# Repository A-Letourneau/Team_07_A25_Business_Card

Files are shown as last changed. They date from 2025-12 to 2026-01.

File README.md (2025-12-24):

# C3I A25\_Business\_Card

Concours de Conception de Circuits Imprimés – Université de Sherbrooke, Automne 2025

## Thème : Carte professionnelle (Business Card)

## Contenu

* Schéma électrique (PDF)
* Fichiers Gerber du PCB + projet EDA OU PDF coloré des couches
* Photo(s) du PCB assemblé (avec et sans boîtier)
* BOM conforme aux normes C3I
* Documentation complète du projet

---

## Contacts

* Alexis Létourneau – Participant – `leta0145@usherbrooke.ca`

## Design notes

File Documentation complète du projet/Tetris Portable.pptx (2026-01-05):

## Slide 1

Tetris portable

Présentation par : équipe 7
Alexis Létourneau
Groupe technique C3I

## Déroulement de la présentation

C3I – Votre nom d’équipe

1

Présentation globale

2

Présentation du projet

3

Respect des contraintes

4

Démonstration

5

Période de
questions

## Présentation globale

- Tetris 9x16
- Portable
- Alimenté par un téléphone
- Peu cher

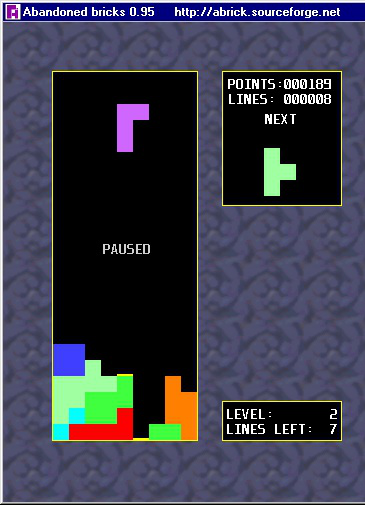
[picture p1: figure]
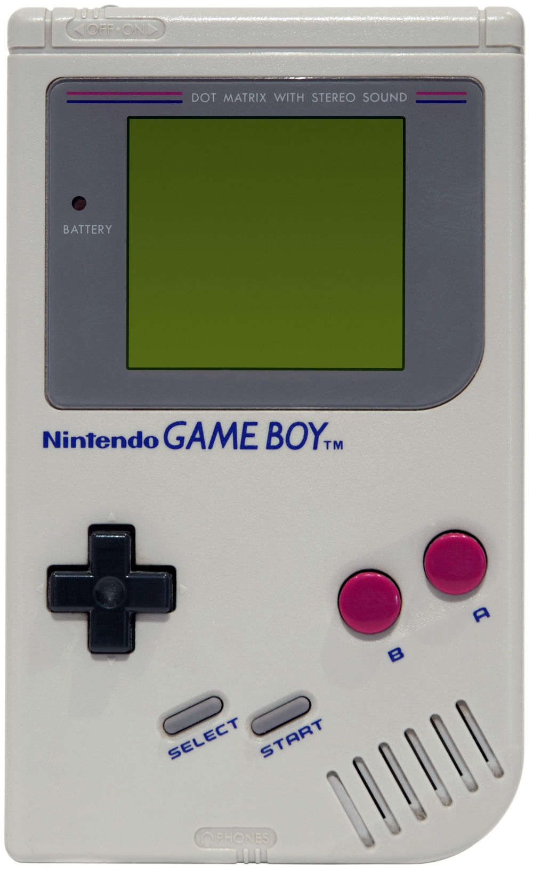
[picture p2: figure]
Looking Back on Nintendo's Game Boy 25 Years Later - Newegg Insider

C3I – Alexis Létourneau

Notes: 26.37$

## Déroulement de la présentation

1

Présentation globale

2

Présentation du projet

3

Respect des contraintes

4

Démonstration

5

Période de
questions

## Le ESP32-C3-WROOM-02

- Communication I2c pour le contrôle des DEL
- Facilité d’utilisation
- Facilité d’intégration
- Pull up intégrée

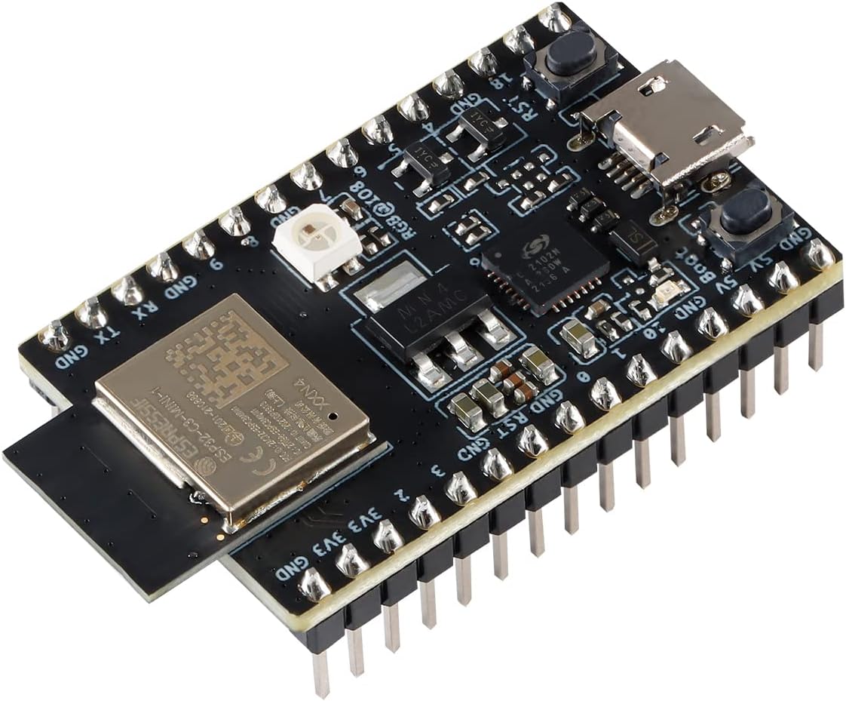
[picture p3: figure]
Esp32 C3 Dev Board

## Programmation

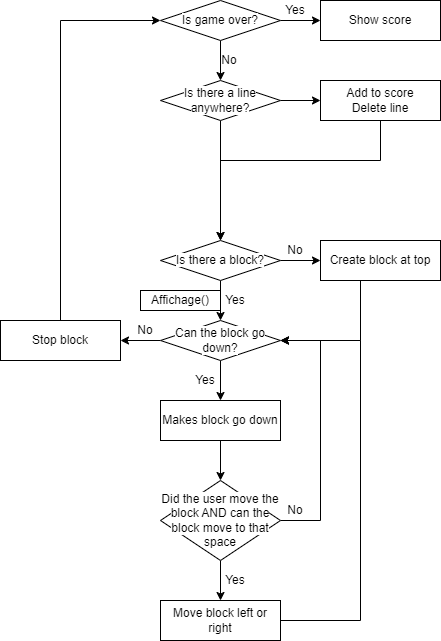
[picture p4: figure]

## PCB

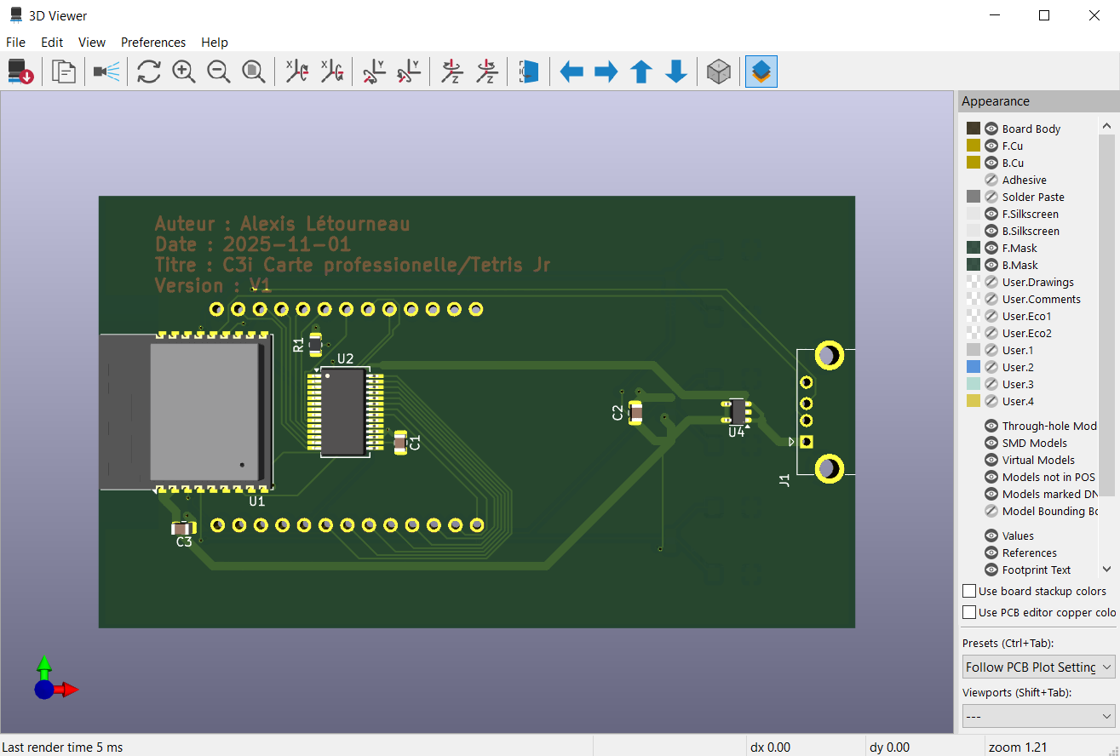
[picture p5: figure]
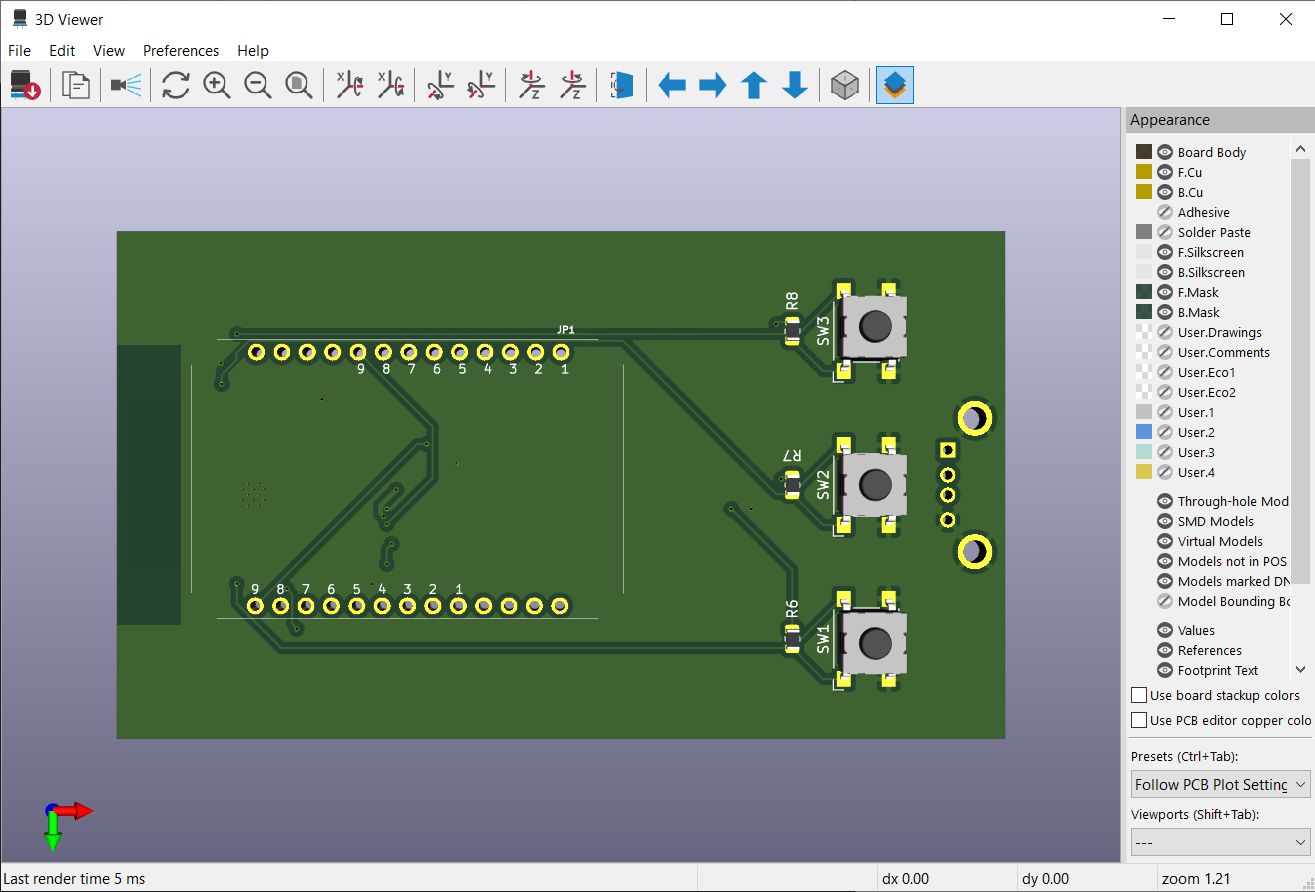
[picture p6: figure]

## Déroulement de la présentation

1

Présentation globale

2

Présentation du projet

3

Respect des contraintes

4

Démonstration

5

Période de
questions

## Respect des contraintes

- Budget
  - Pièces électroniques
  - PCB
- Taille
  - Ergonomique

## Déroulement de la présentation

1

Présentation globale

2

Présentation du projet

3

Respect des contraintes

4

Démonstration

5

Période de
questions

## Démo!

- Expliquez brièvement comment utiliser votre produit, puis faites une démonstration. Il se peut que les juges tests votre produit aussi.
- 1 slide

## Déroulement de la présentation

1

Présentation globale

2

Présentation du projet

3

Respect des contraintes

4

Démonstration

5

Période de
questions

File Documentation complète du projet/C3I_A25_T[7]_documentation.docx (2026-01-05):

UNIVERSITÉ DE SHERBROOKE

Groupe technique

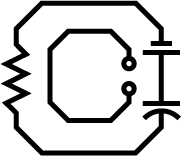
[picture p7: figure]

Compétition de Conception de

Circuits Imprimés

# Documentation C3I A25

Tetris Portable

Rédigé par :

Équipe #7,

Alexis Létourneau

En date du : 5 janvier 2026

Table des matières

# 1. Introduction

## Contexte d’application

Le projet est un jeu de Tetris Portable de la taille d’une carte professionnelle. Il sera utilisé d’une manière similaire à une « Gameboy » mais avec un seul jeu de Tetris. L’idée est d’avoir une toute petite carte qui peut démontrer mon savoir de PCB en utilisant un jeu connu par la plupart de la population. Un client utiliserait la carte en branchant la prise USB de la carte dans une source de tension, comme un bloc-chargeur de téléphone, et puis appuiera sur les 3 boutons pour jouer au jeu. Pour plus d’information sur comment jouer à Tetris : https://fr.wikihow.com/jouer-%C3%A0-Tetris. Il faut noter que la fonction pivoter ne marche pas pour ce projet.

## Contraintes du projet

### 1.1.1. Contraintes technologiques

Le C3I limite la taille du PCB à 88,9 mm x 50,8 mm et enlève des points avec l’utilisation d’un « DevBoard ». Cela fait que la carte peut au mieux contenir un petit MCU, comme un ESP-32. La petite taille limite aussi l’ergonomie et la quantité des contrôles actionnables, comme les boutons, sur le PCB

### 1.1.2. Contraintes de temps et de budget

Le cout totale de la session était 125$, dont 50$ maximale en pièces électroniques. Cela était amplement assez pour couvrir les frais des pièces électroniques, même avec des pièces électroniques en extra.

Le temps lui était plus serré, même si nous avions la session au complet, la commande de PCB et des pièces électroniques s’est fait en mi-novembre. La mi-novembre est aussi la période la plus chargé en termes de projet en génie et d’examen.

## Description du produit réalisé

Ma carte professionnel de Tetris portable est contrôlé par un microcontrôleur ESP32-WROOM-32E qui lui contrôle un contrôleur IS31FL3731-SA. Le IS31FL3731-SA contrôle l’affichage de 144 DEL Charlie-Plex via I2c pour afficher le jeu de Tetris. Le microcontrôleur est alimenté par une prise USB-A 5V qui est ensuite réduit à 3.3V avec un régulateur de tension. Finalement, il y a 3 boutons pour interagir avec le jeu de Tetris.

### 1.1.3. Présentation globale

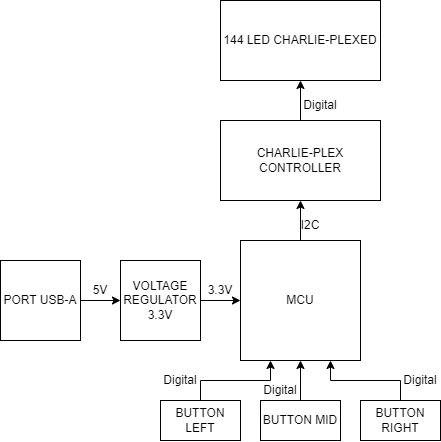
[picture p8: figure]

# 2. Développement

## Conception électronique

### 2.1.1. Choix technologiques

J’ai choisi un ESP32-WROOM-32E comme microcontrôleur car je suis familier avec son utilisation et il supporte la communication I2c pour contrôler l’affichage de DEL.

L’affichage avec des DEL « Charlie-plexed » a été choisi au lieu d’un affichage LCD pour simplifier le branchement et pour réduire la demande en alimentation. La configuration des DEL 9 x 16 est aussi la plus proche du jeu Tetris original.

Le contrôleur de DEL « Charlie-plexed » existe pour réduire le nombre d’entrées/sorties car il seulement besoin d’alimentation et d’une connexion I2c. Sans le contrôleur, le microcontrôleur aurait besoin d’avoir 18 entrées/sorties.

### 2.1.2. Schémas électriques et conception PCB

Annexe A [Schéma électrique 1/3] : Connexion avec le MCU et le contrôleur de DEL.

Annexe B [Schéma électrique 2/3] : Connexion des DEL Charlie-Plexed.

Annexe C [Schéma électrique 3/3] : Connexion de l’alimentation.

Annexe D [PCB vue du haut] : Contient le ESP-32, le régulateur de tension, le port USB-A et le contrôleur de DEL.

Annexe E [PCB vue du bas] : Contient la matrice de DEL Charlie-Plexed et les 3 boutons.

## Conception informatique

### 2.1.3. Présentation globale du code

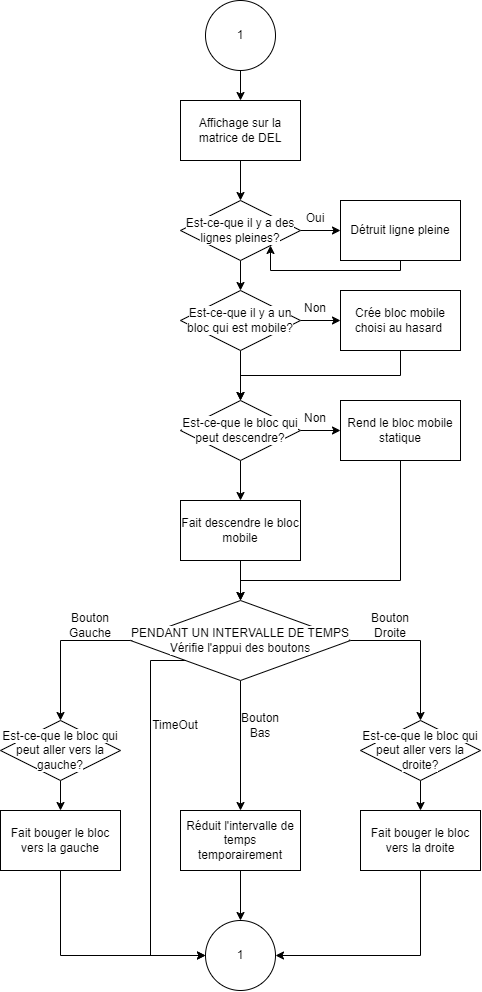
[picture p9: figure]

Figure 1 : Schéma fonctionnel Tetris

Le code fonctionne de façon séquentiel en vérifiant l’état d’un tableau et en ajustant selon les interactions du joueur. Un tableau contenant des « 1 » pour les blocs statiques et « 2 » pour les blocs mobiles sert pour visualiser l’état du jeu. À chaque intervalles de temps, 250ms par défaut, la série de logique se répète. La communication I2c se fait avec les 3 librairies inclut.

### 2.1.4. Librairies

Wire.h : La librairie pour la communication I2c pour le contrôleur de l’affichage de DEL.

Adafruit_GFX.h et Adafruit_IS31FL3731.h : Les librairies pour contrôler les pixels de l’affichage de DEL.

## Gestion

### 2.1.5. Temps

Après avoir reçu les pièces électroniques et le PCB en mi-novembre, le prototypage s’est fait rapidement, mais la fin de session avait commencé et elle a été particulièrement brutale, donc la soudure n’a pas pu se faire avant la fin des cours. Malheureusement, le studio de création était fermé durant les fêtes, donc le PCB n’a pas été fini.

### 2.1.6. Budget

Le budget n’a pas été un problème durant la conception, mes pièces électroniques était tous à bas prix et le budget énorme en comparaison. Même avec l’achat de 2 régulateurs de tension suplémentaire et un devKit du IS31FL3731-SA pour le prototypage sur breadboard, je n’ai pas dépassé le budget.

J’ai dépensé 47,51 $ pour les pièces électroniques. Je n’ai pas information sur le prix du PCB.

# 3. Conclusion

L’idée principale et le produit final est quasiment identique. Un jeu de Tetris affiché sur un affichage de DEL avec trois boutons était le résultat escompté. Par contre, le projet est plus simple que prévu, si j’avais le temps, j’aurais ajouté un boitier et une fonction pour pivoter les bloc pour que le jeu soit plus similaire au Tetris original.

# 4. Références

https://fr.wikihow.com/jouer-%C3%A0-Tetris. : Manuel pour tetris

# Annexe A [Schéma Électrique 1/3]

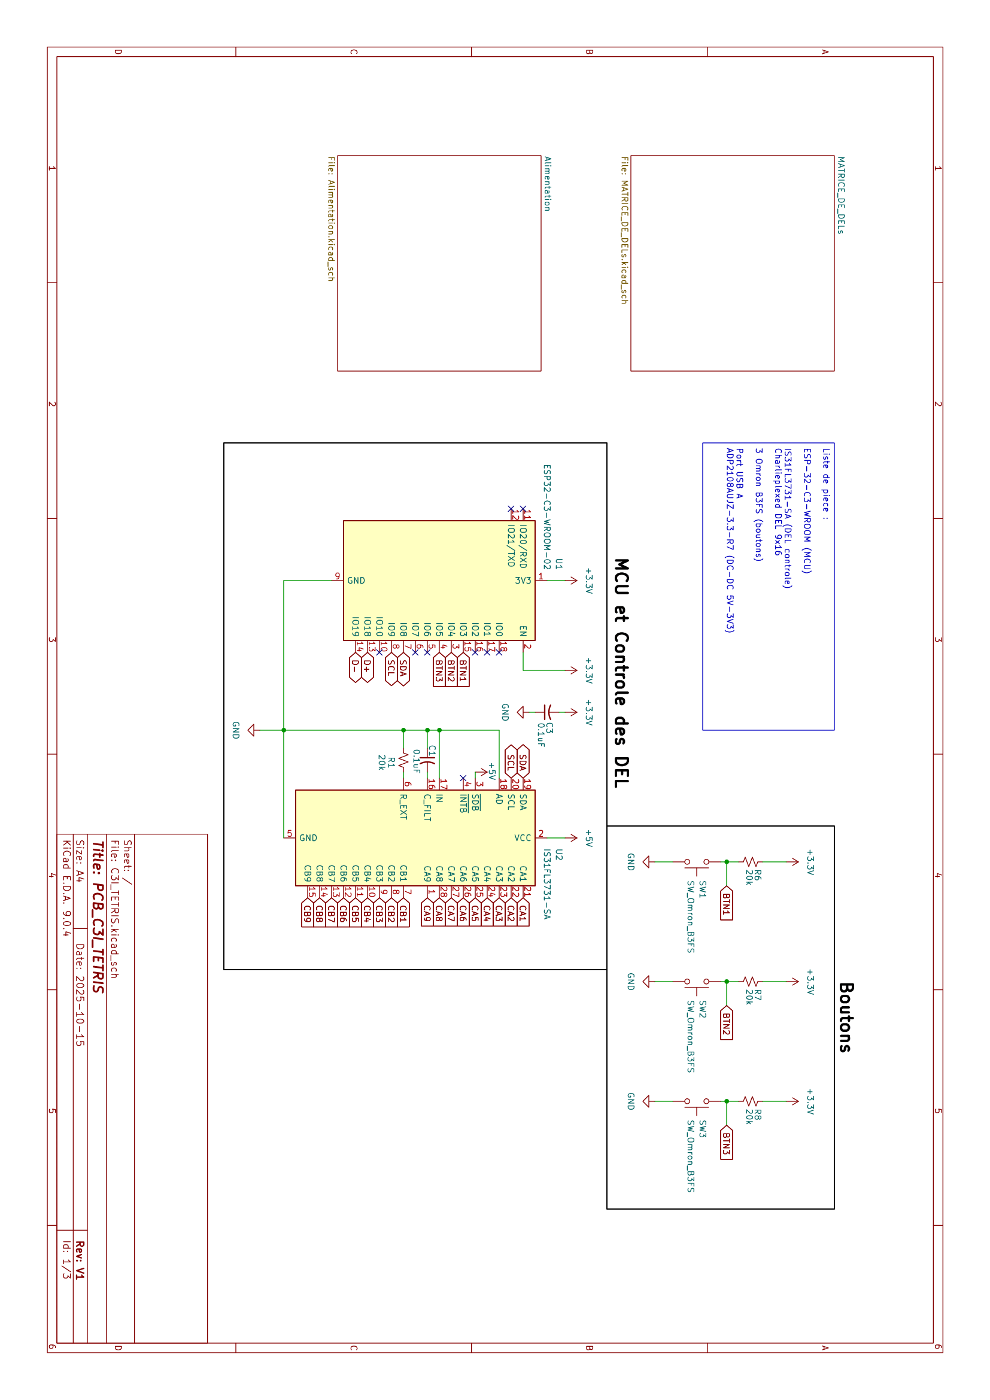
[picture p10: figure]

# Annexe B [Schéma Électrique 2/3]

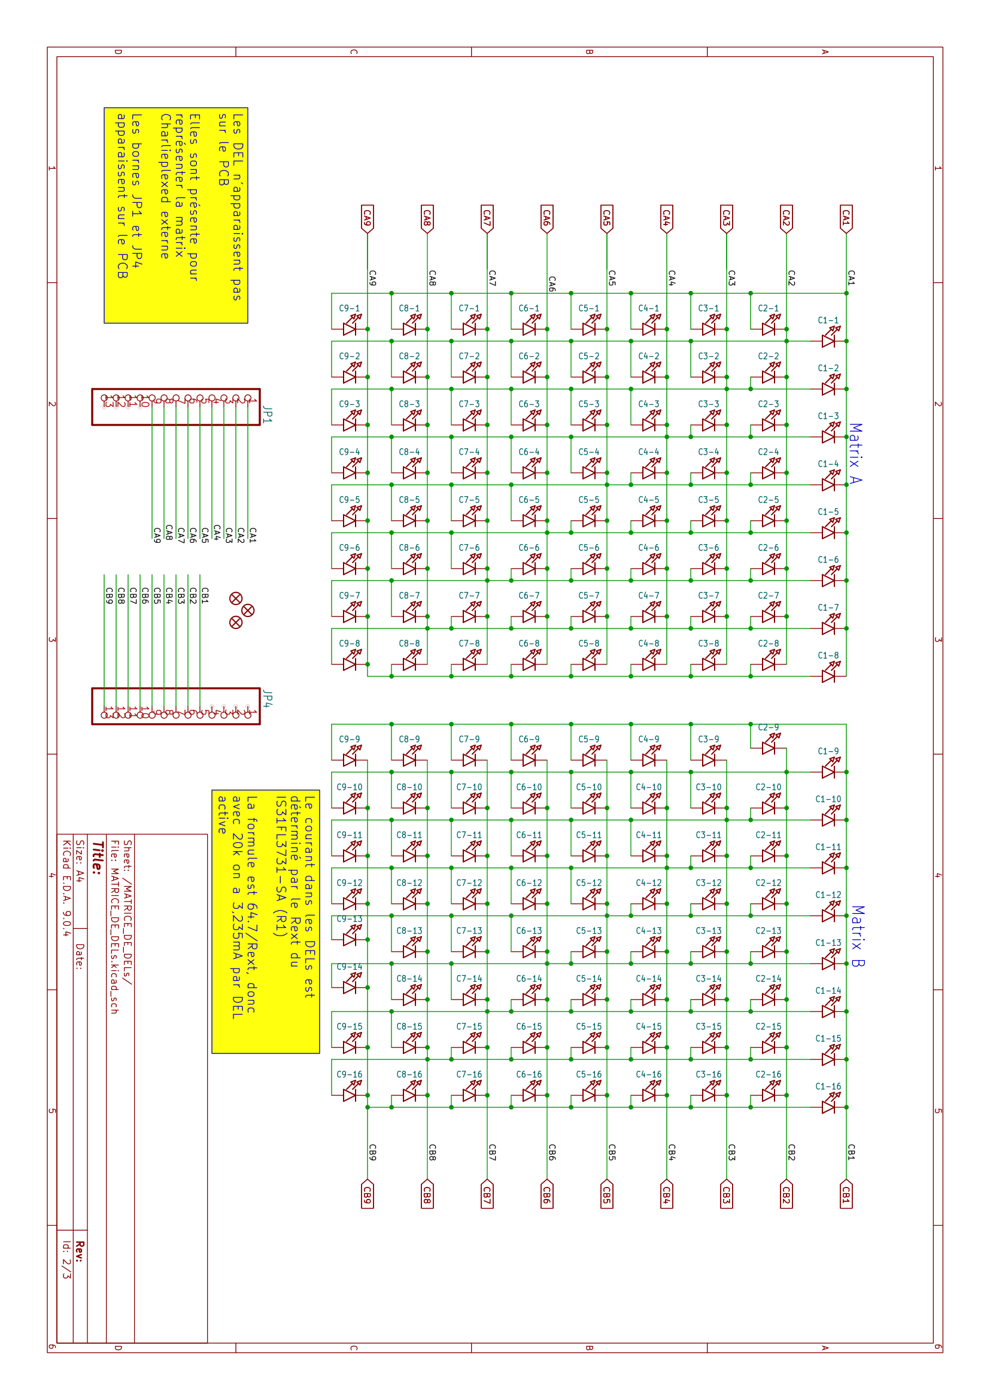
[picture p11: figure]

# Annexe C [Schéma Électrique 3/3]

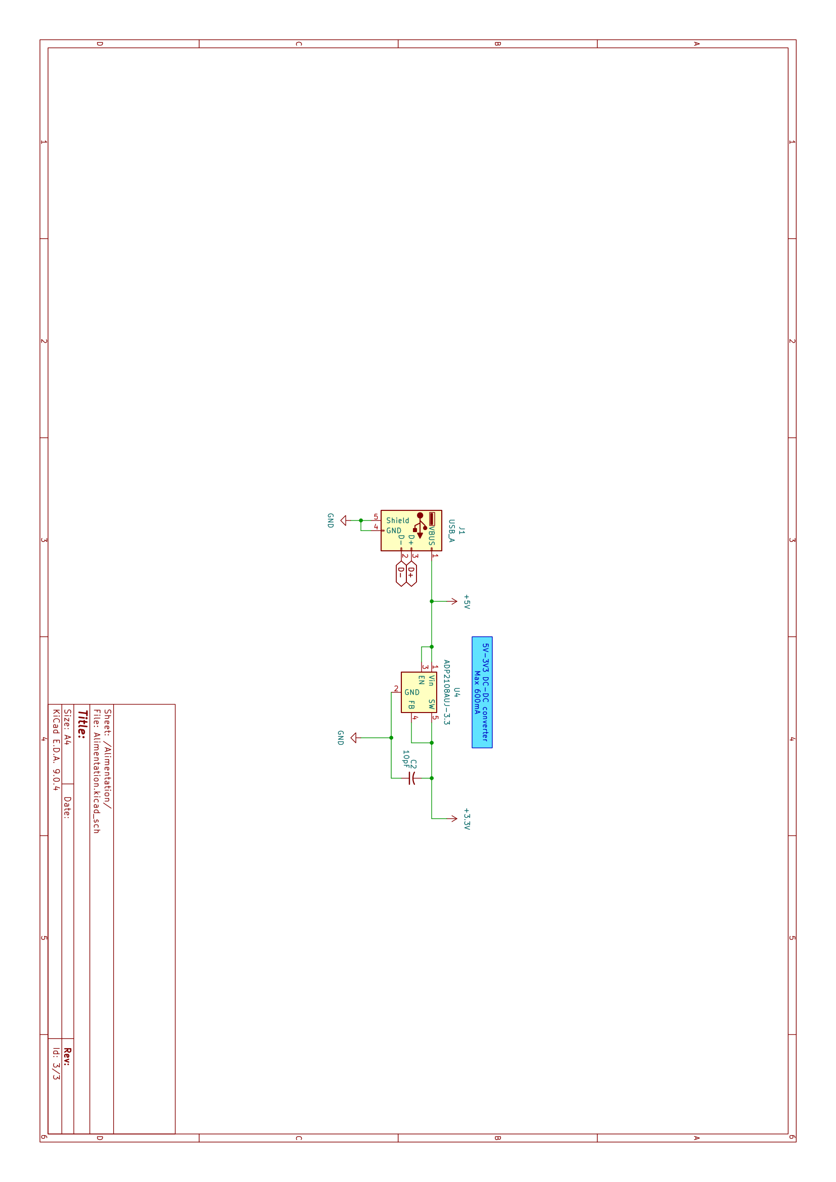
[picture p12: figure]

# Annexe D [PCB vue du haut]

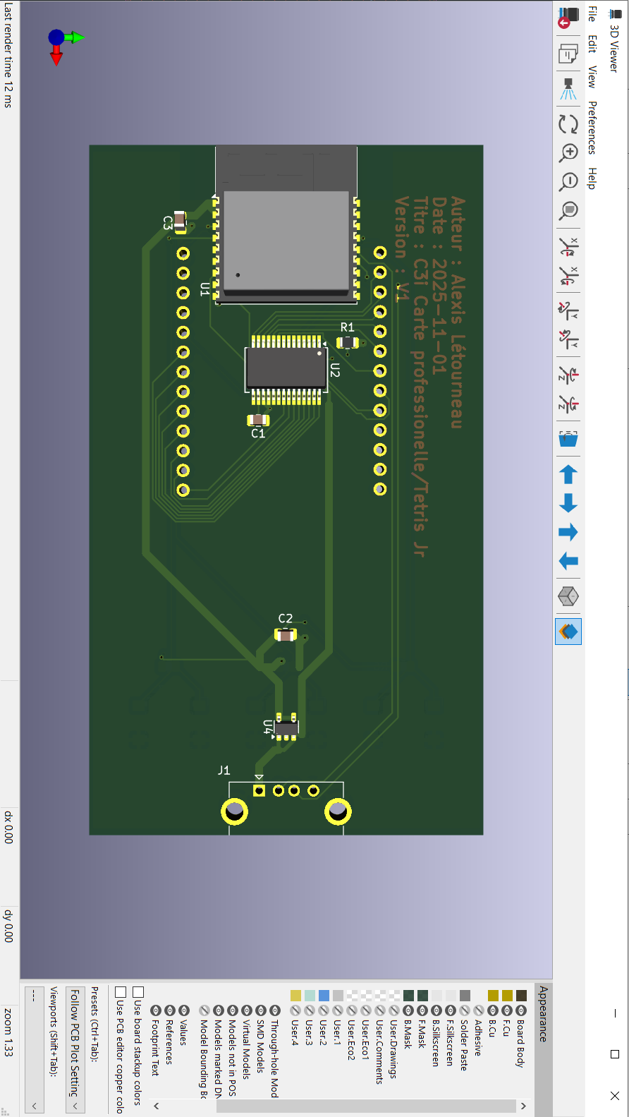
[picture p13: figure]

# Annexe E [PCB vue du bas]

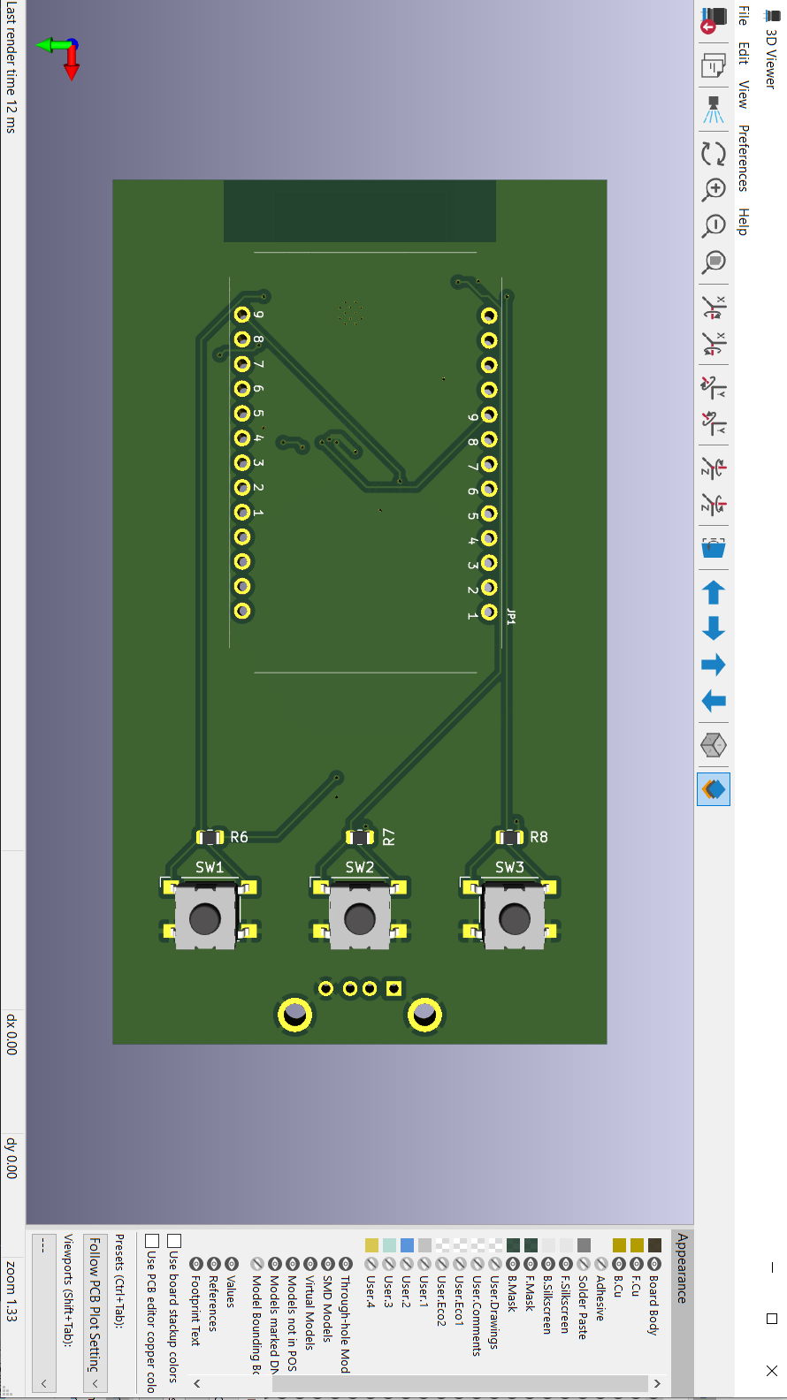
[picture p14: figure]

2 documentation C3I 5 janvier 2026 [Titre du document]

Compétition de Circuits Imprimés

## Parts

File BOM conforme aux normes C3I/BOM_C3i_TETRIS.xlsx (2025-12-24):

Reference | Qty | Value | DNP | Exclude from BOM | Exclude from Board | Footprint | Datasheet
C1,C3 | 2 | 0.1uF |  |  |  | Capacitor_SMD:C_0805_2012Metric
JP1,JP4 | 1 | CharliePlexed LED MATRIX |  |  |  | Adafruit IS31FL3731 CharliePlex Grid:CHIPLED_0603_NOOUTLINE
C2 | 1 | 10pF |  |  |  | Capacitor_SMD:C_0805_2012Metric
J1 | 1 | USB_A |  |  |  | Connector_USB:USB_A_Kycon_KUSBX-AS1N-B_Horizontal | ~
R1,R6,R7,R8 | 4 | 20k |  |  |  | Resistor_SMD:R_0805_2012Metric | ~
SW1,SW2,SW3 | 3 | SW_Omron_B3FS |  |  |  | Button_Switch_SMD:SW_SPST_Omron_B3FS-100xP | https://omronfs.omron.com/en_US/ecb/products/pdf/en-b3fs.pdf
U1 | 1 | ESP32-C3-WROOM-02 |  |  |  | RF_Module:ESP32-C3-WROOM-02 | https://www.espressif.com/sites/default/files/documentation/esp32-c3-wroom-02_datasheet_en.pdf
U2 | 1 | IS31FL3731-SA |  |  |  | Package_SO:SSOP-28_5.3x10.2mm_P0.65mm | http://www.issi.com/WW/pdf/31FL3731.pdf
U4 | 1 | ADP2108AUJ-3.3 |  |  |  | Package_TO_SOT_SMD:TSOT-23-5 | https://www.analog.com/media/en/technical-documentation/data-sheets/ADP2108.pdf

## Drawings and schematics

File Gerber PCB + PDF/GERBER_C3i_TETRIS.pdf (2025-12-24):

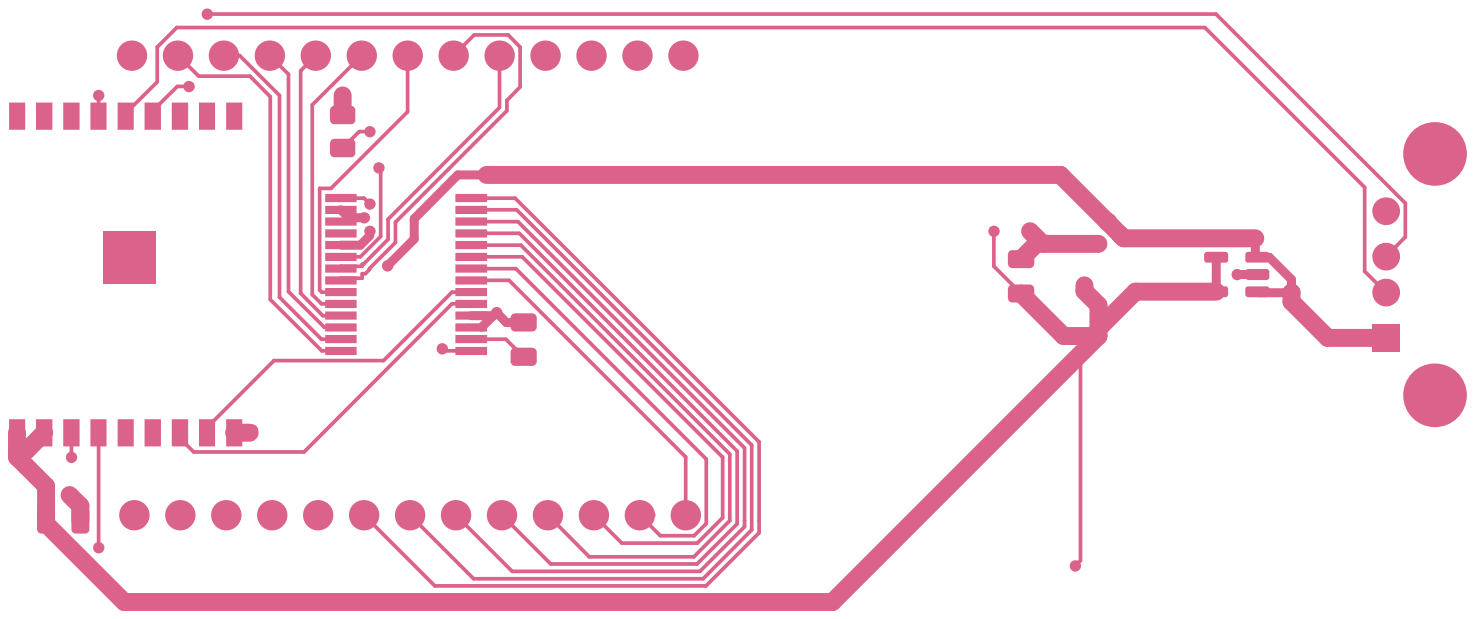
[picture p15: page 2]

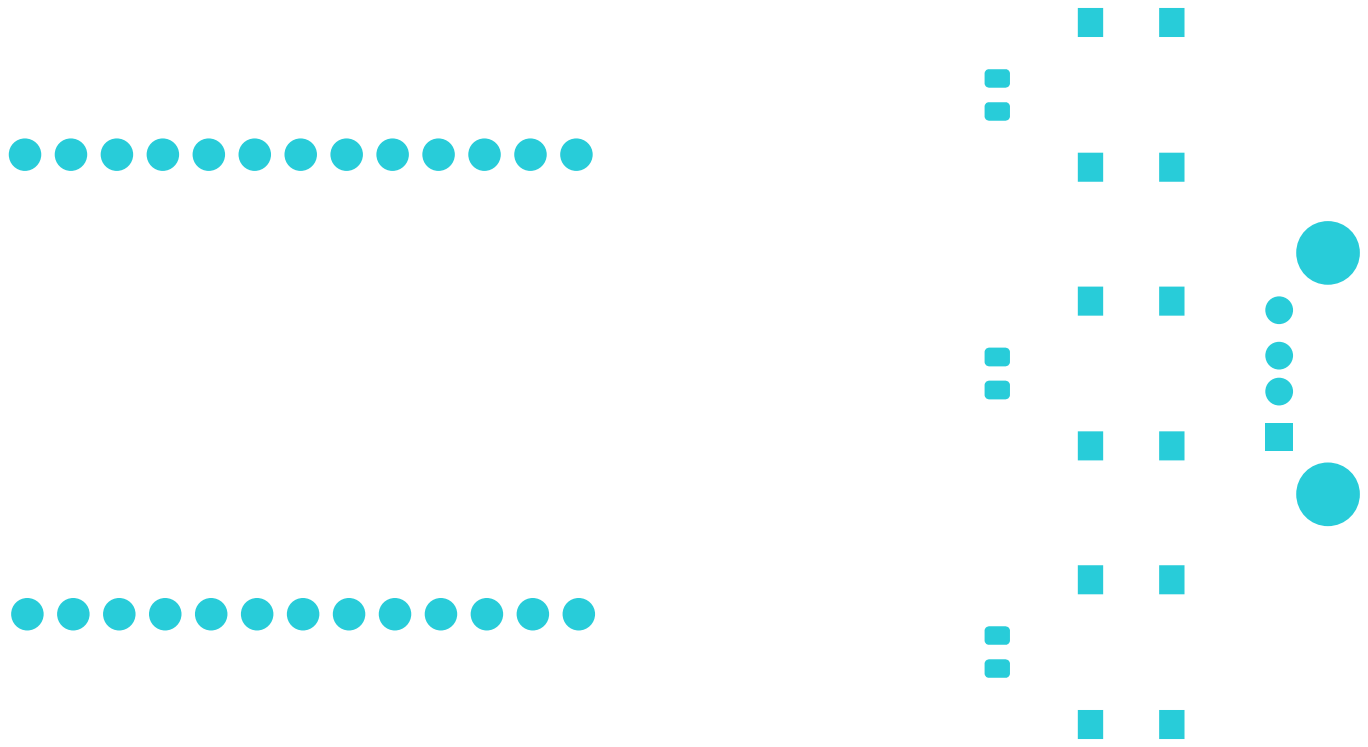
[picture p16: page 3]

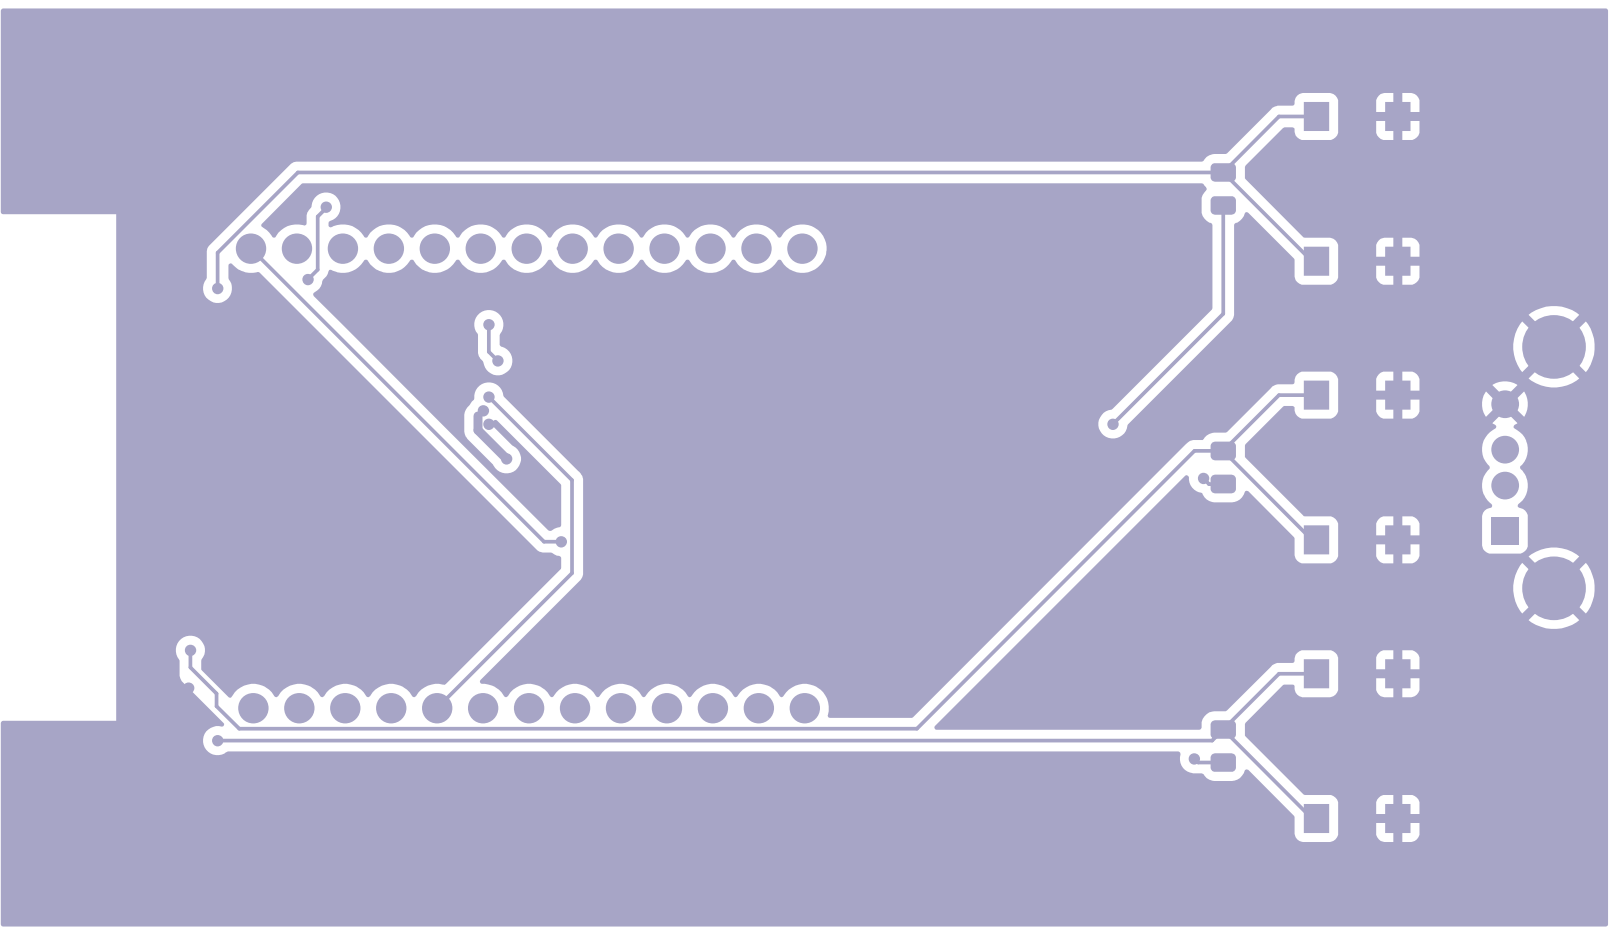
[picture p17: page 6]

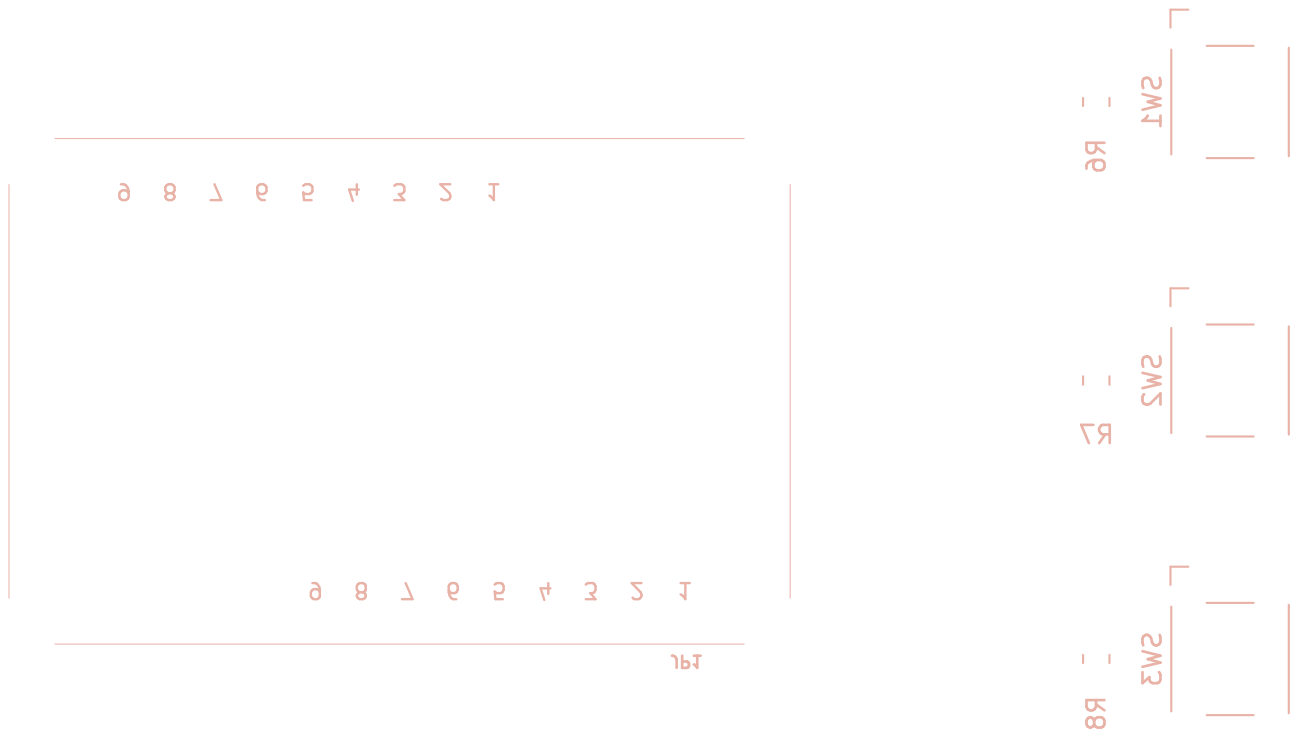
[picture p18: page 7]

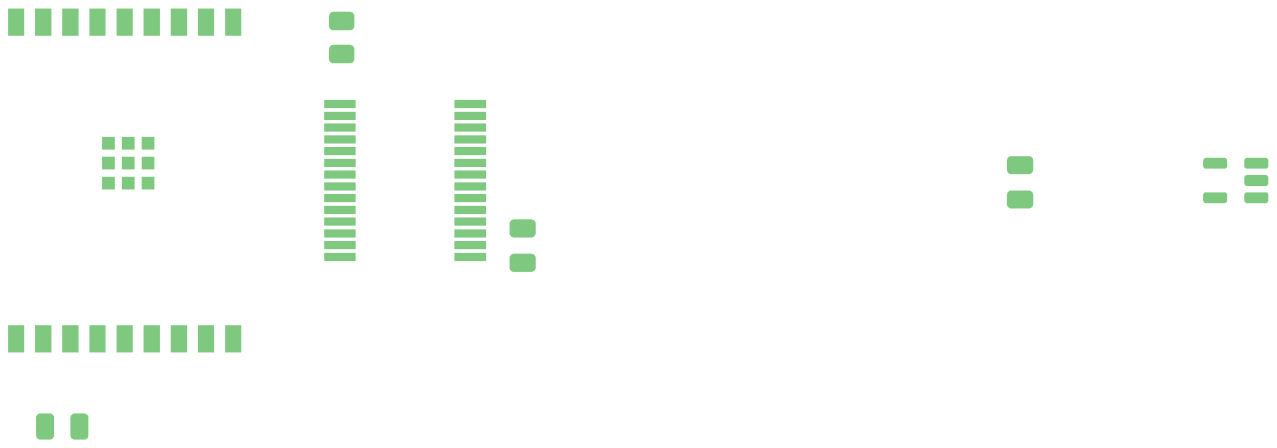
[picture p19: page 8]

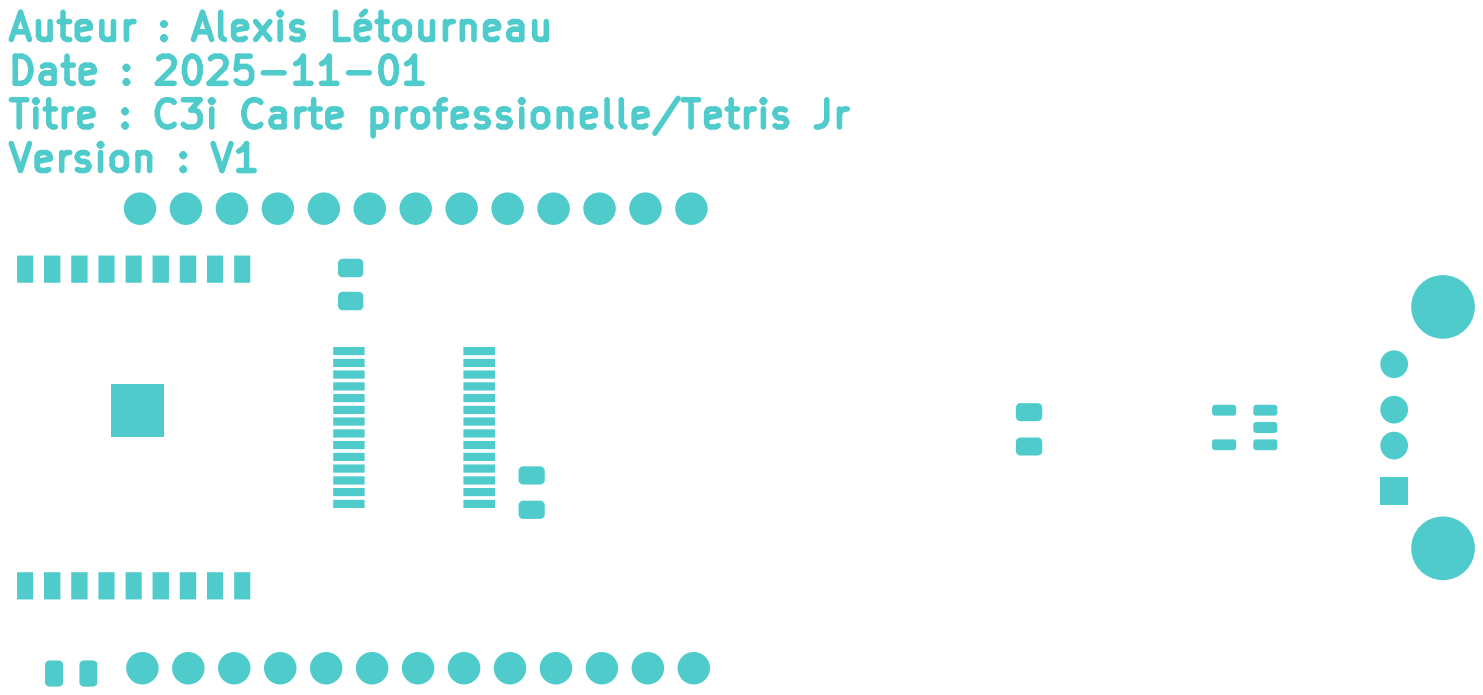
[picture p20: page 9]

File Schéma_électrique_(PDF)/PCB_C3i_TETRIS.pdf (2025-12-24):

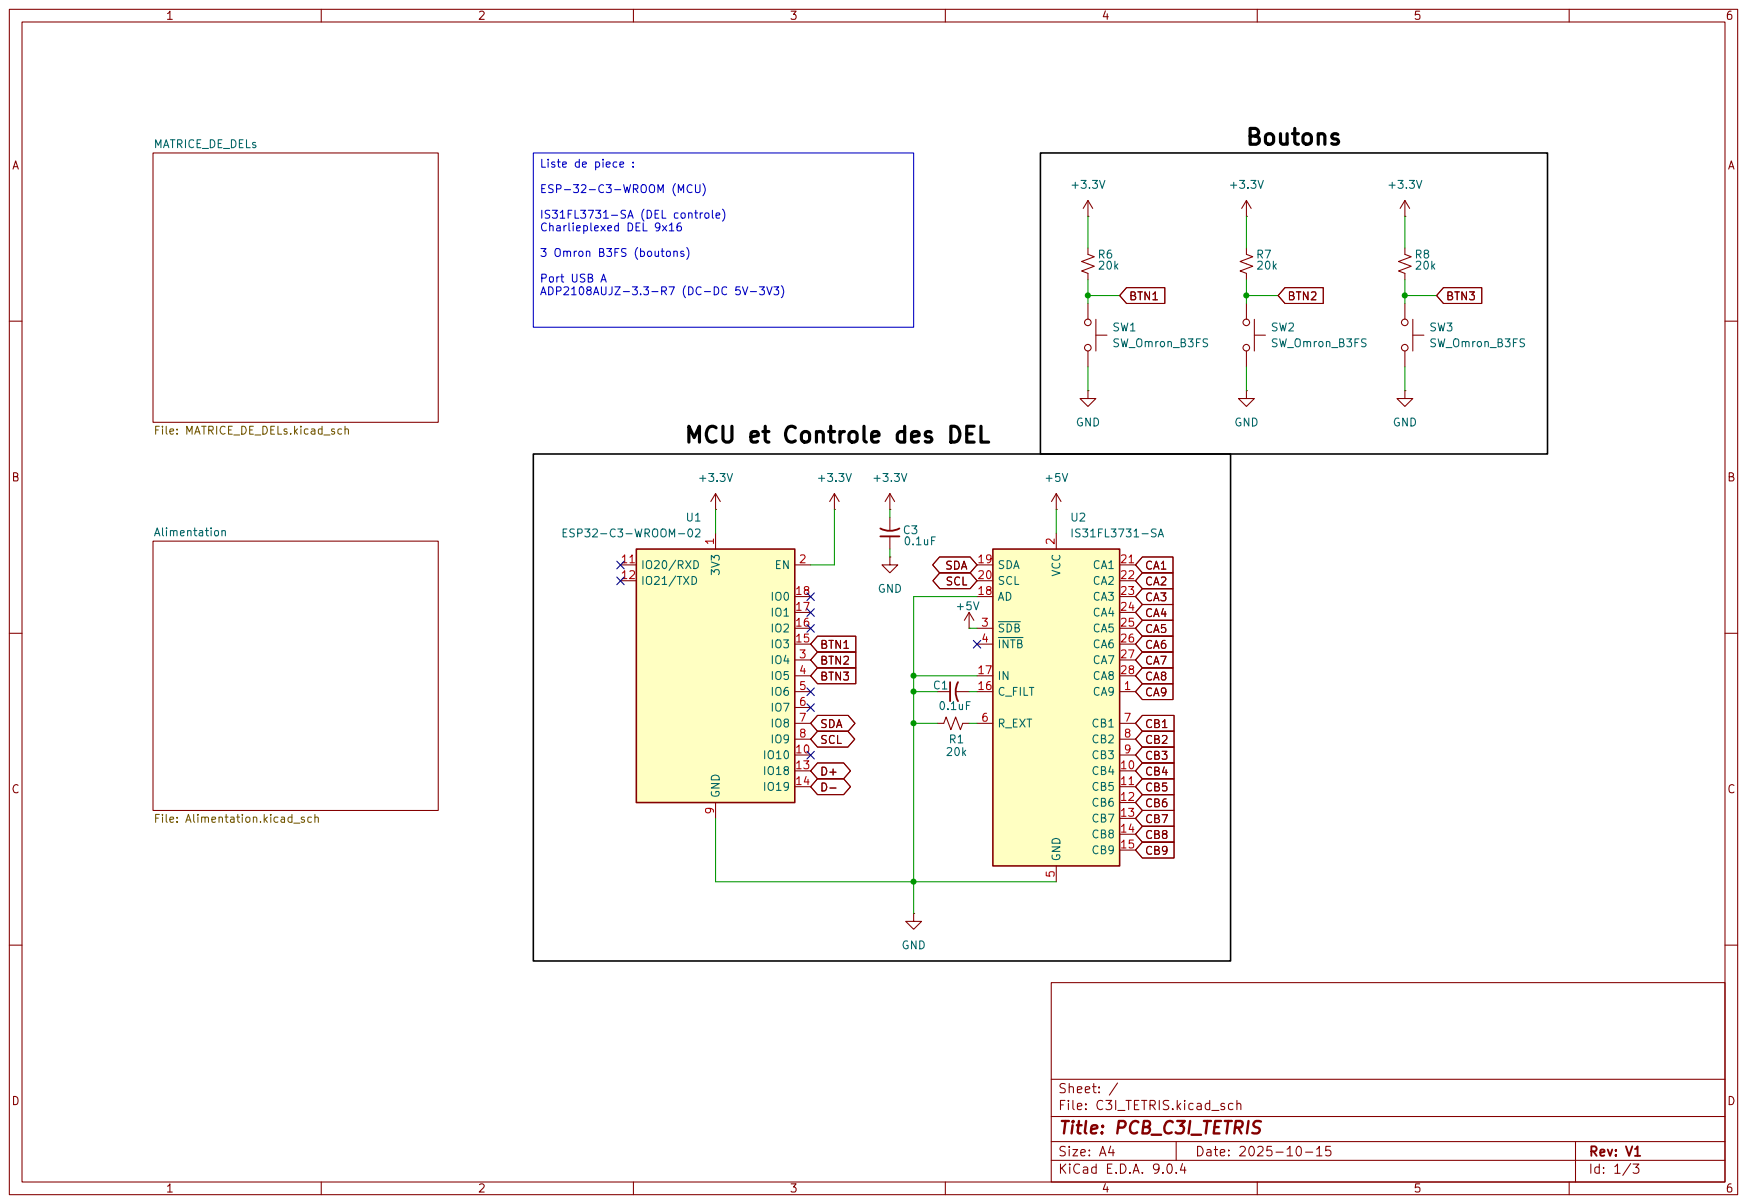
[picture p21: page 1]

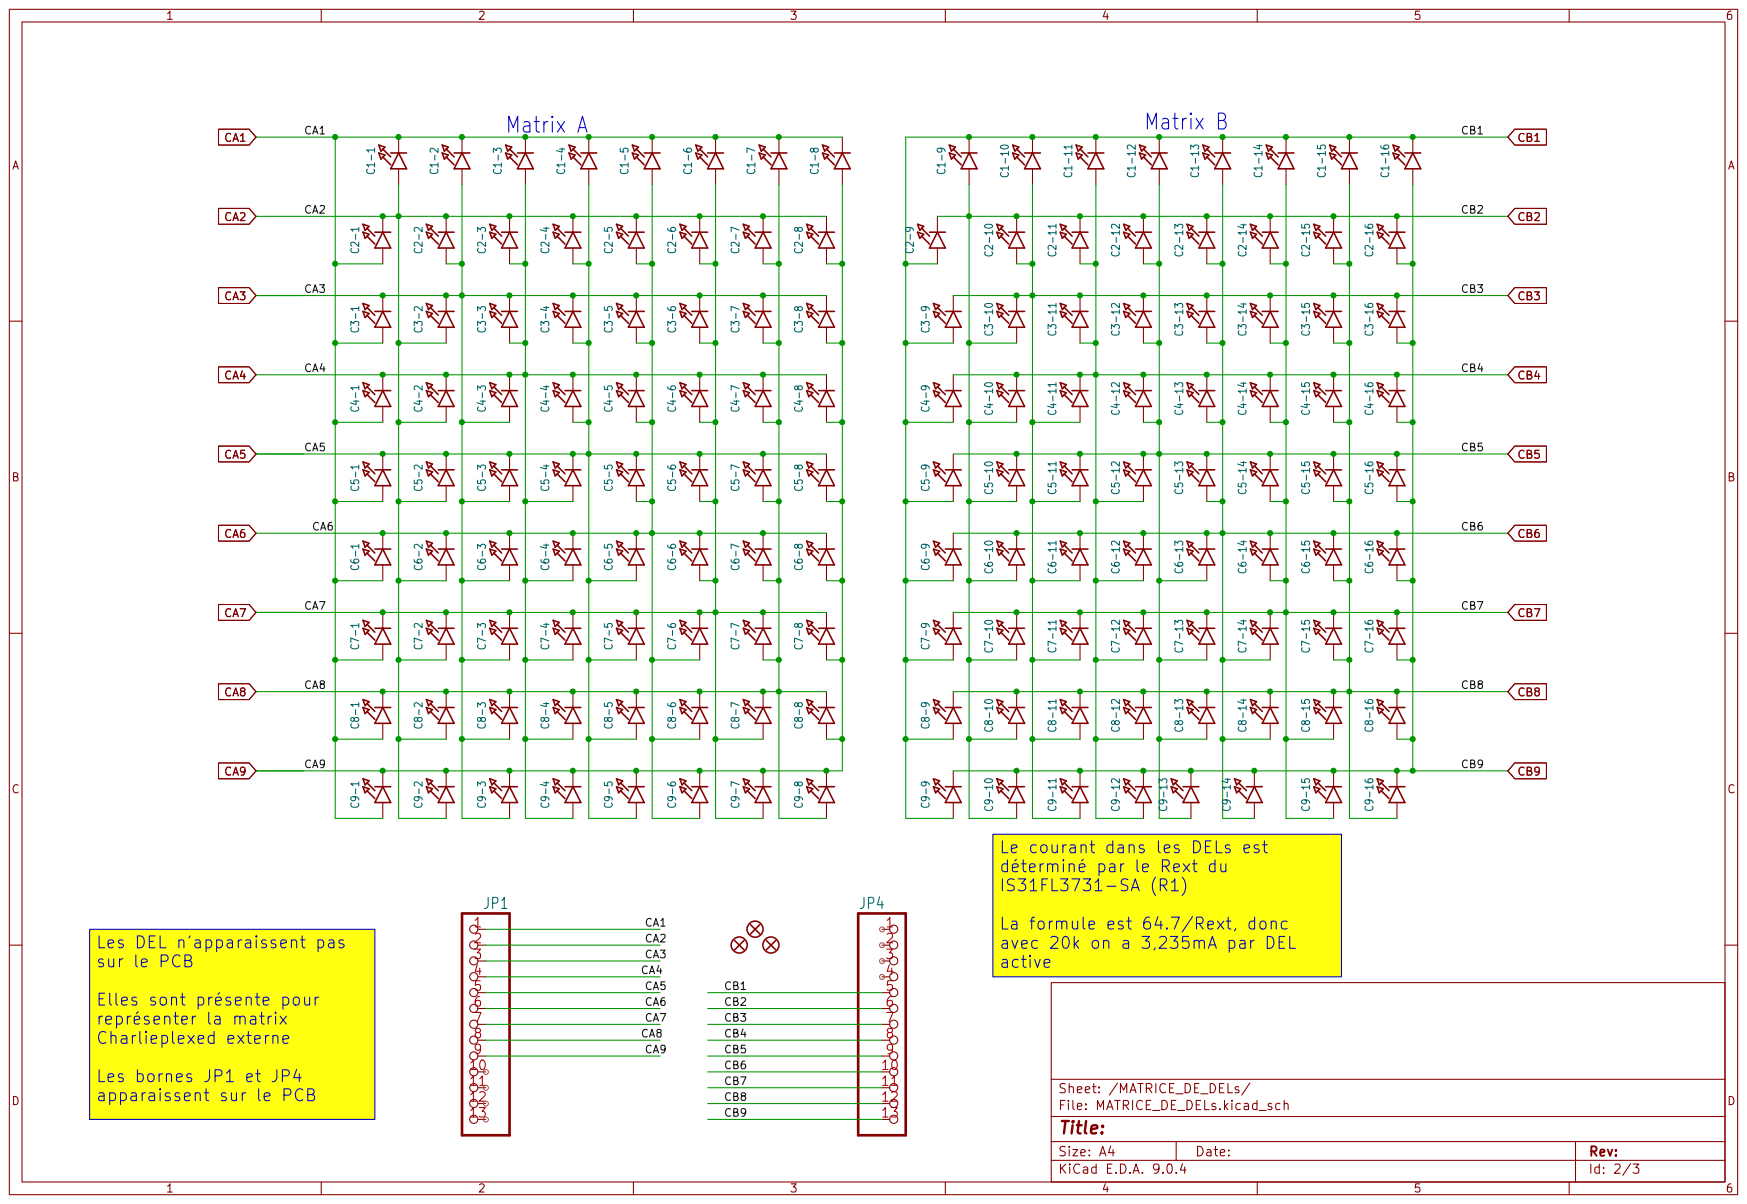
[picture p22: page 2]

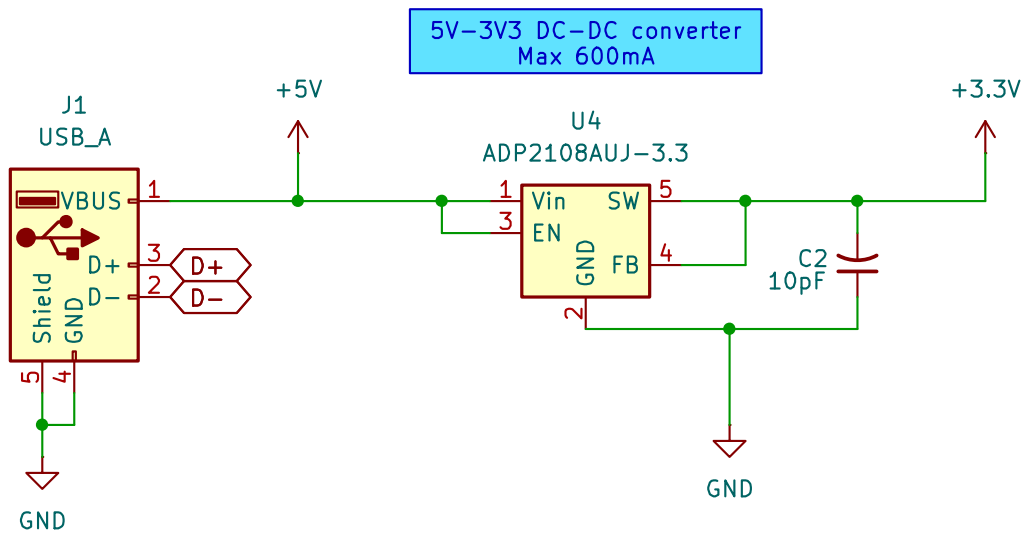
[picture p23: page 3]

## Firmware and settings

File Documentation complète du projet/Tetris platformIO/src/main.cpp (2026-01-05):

/*
Auteur : Alexis Létourneau
Date : 2026-01-05
Brief : Tetris sur une matrice de DEL de 9x16

Veuiller importer les 3 librairie avec platform.io
*/


#include <Wire.h>
#include <Adafruit_GFX.h>
#include <Adafruit_IS31FL3731.h>

#define nbRow 16 + 3
#define nbCol 9

#define LIGHT_LEVEL 3

#define EMPTY 0
#define SQUARE 1
#define MOVING_BLOCK 2
#define START_LAYER 15

#define BUTTON_LEF_PIN 23
#define BUTTON_MID_PIN 19
#define BUTTON_RIG_PIN 18

#define NB_OF_SIZE_1_BLOCK 1
#define NB_OF_SIZE_2_BLOCK 7
#define NB_OF_SIZE_3_BLOCK 6
#define NB_OF_SIZE_4_BLOCK 0

#define LINE_CLEAR_DELAY 100 //*3*3



// If you're using the full breakout...
Adafruit_IS31FL3731 ledmatrix = Adafruit_IS31FL3731();
// If you're using the FeatherWing version
//Adafruit_IS31FL3731_Wing ledmatrix = Adafruit_IS31FL3731_Wing();


uint8_t board[nbRow][nbCol] = {{}};

uint32_t speed = 250;
uint32_t startTime = 0;

uint8_t score = 0;

uint8_t xBlock = 0;
uint8_t yBlock = 0;

uint8_t sizeOfBlock = 0;

void affichage(){
  uint8_t light = 0;
  // animate over all the pixels, and set the brightness from the sweep table
  for (uint8_t x = 0; x < nbRow - 3; x++)
    for (uint8_t y = 0; y < nbCol; y++)
    {
      if (board[x][y] != 0)
        light = LIGHT_LEVEL;
      else
        light = 0;

      if (x >= 8)
        ledmatrix.drawPixel(-x + 23, -y + 8, light);
      else
        ledmatrix.drawPixel(x, y, light);
    }
}

void checkGameOver(){
  for (uint8_t y = 0; y < nbCol; y++)
    if (board[START_LAYER][y] == 1)
      for (uint8_t x = 0; x < nbRow; x++)
        for (uint8_t y = 0; y < nbCol; y++)
          board[x][y] = 0;
}

void stopBlock(){
    for (uint8_t x = 0; x < nbRow; x++)
      for (uint8_t y = 0; y < nbCol; y++)
        if (board[x][y] == MOVING_BLOCK)
          board[x][y] = SQUARE;
  }

bool checkMovingBlock(){
  int isBlock = false;
  for (uint8_t x = 0; x < nbRow; x++)
    for (uint8_t y = 0; y < nbCol; y++)
      if (board[x][y] == MOVING_BLOCK)
        isBlock = true;

  return isBlock;
}

void createBlock(){
  const uint8_t size_2_Blocks[NB_OF_SIZE_2_BLOCK][3][2] = {
      {   
        { 0, 0 }, //Square
        { 2, 2 },
        { 2, 2 } 
      },
      {   
        { 2, 0 }, //T 
        { 2, 2 },
        { 2, 0 } 
      },
      {   
        { 0, 2 }, //T mirror
        { 2, 2 },
        { 0, 2 } 
      },
      {   
        { 2, 0 }, //L
        { 2, 0 },
        { 2, 2 } 
      },
      {   
        { 0, 2 }, //L mirror
        { 0, 2 },
        { 2, 2 } 
      },
      {   
        { 0, 2 }, //S
        { 2, 2 },
        { 2, 0 } 
      },
      {   
        { 2, 0 }, //Z
        { 2, 2 },
        { 0, 2 } 

      }
    };

  const uint8_t size_3_Blocks[NB_OF_SIZE_3_BLOCK][2][3] = {
      {
        { 0, 2, 0 }, //T
        { 2, 2, 2 } 
      },
      {
        { 2, 2, 2 }, //T mirror
        { 0, 2, 0 } 
      },
      {
        { 0, 2, 2 }, //Z
        { 2, 2, 0 } 
      },
      {
        { 2, 2, 0 }, //S
        { 0, 2, 2 } 
      },
      {
        { 0, 0, 2 }, //L
        { 2, 2, 2 } 
      },
      {
        { 2, 0, 0 }, //L mirroir
        { 2, 2, 2 } 
      }
    };

  uint8_t typeOfBlock = random(1, NB_OF_SIZE_1_BLOCK + NB_OF_SIZE_2_BLOCK + NB_OF_SIZE_3_BLOCK + NB_OF_SIZE_4_BLOCK );
  uint8_t posYSpawn = 0;
  uint8_t randoBlock = 0;

  if (typeOfBlock == 1)
  {
    Serial.println("Spawn line ");
    posYSpawn = random(0, nbCol);
    for (uint8_t x = START_LAYER; x < nbRow; x++)
      board[x][posYSpawn] = MOVING_BLOCK;
    sizeOfBlock = 1;
  }
  else if(typeOfBlock > 1 && typeOfBlock < NB_OF_SIZE_1_BLOCK + NB_OF_SIZE_2_BLOCK)
  {
    sizeOfBlock = 2;
    Serial.println("Spawn size 2 blocks ");
    posYSpawn = random(0, nbCol - 1);
    randoBlock = random(0, NB_OF_SIZE_2_BLOCK);
    for (uint8_t x = START_LAYER; x < START_LAYER + 3; x++)
      for (uint8_t y = posYSpawn; y < sizeOfBlock + posYSpawn; y++)
        board[x][y] = size_2_Blocks[randoBlock][x - START_LAYER][y - posYSpawn];
  }
  else if(typeOfBlock > NB_OF_SIZE_1_BLOCK + NB_OF_SIZE_2_BLOCK && typeOfBlock < NB_OF_SIZE_1_BLOCK + NB_OF_SIZE_2_BLOCK + NB_OF_SIZE_3_BLOCK)
  {
    sizeOfBlock = 3;
    Serial.println("Spawn size 3 blocks ");
    posYSpawn = random(0, nbCol - 2);
    randoBlock = random(0, NB_OF_SIZE_3_BLOCK);
    for (uint8_t x = START_LAYER; x < START_LAYER + 2; x++)
      for (uint8_t y = posYSpawn; y < sizeOfBlock + posYSpawn; y++)
        board[x][y] = size_3_Blocks[randoBlock][x - START_LAYER][y - posYSpawn];

  }

    xBlock = START_LAYER;
    yBlock = posYSpawn;
}

void makeBlockDown(){
  for (uint8_t x = 0; x < nbRow; x++)
  {
    for (uint8_t y = 0; y < nbCol; y++)
    {
      if (board[x][y] == MOVING_BLOCK)
      {
        board[x-1][y] = MOVING_BLOCK; 
        board[x][y] = EMPTY;
      }
    }
  }
  xBlock -= 1;
}

bool checkBlockDown(){
  for (uint8_t x = 0; x < nbRow; x++)
  {
    for (uint8_t y = 0; y < nbCol; y++)
    {
      if (board[x][y] == MOVING_BLOCK)
      {
        if (x > 0)
        {
          if (board[x-1][y] == SQUARE)
            return false;
        }
        else
          return false;
      }
    }
  }
  return true;
}

bool checkBlockLorR(char dir){
  if (dir == 'L')
  {
    if (yBlock - 1 < 0)
    {
      Serial.println("Cant move, on the left edge");
      return false;
    }
    for(uint8_t x = 0; x < nbRow; x++)
      {
        if (board[x][yBlock - 1] == SQUARE && board[x][yBlock] == MOVING_BLOCK)
        {
          Serial.println("Cant move, block in the way");
          return false;
        }
      }
  }
  else if (dir == 'R')
  {
    if (yBlock + sizeOfBlock >= nbCol)
    {
      Serial.println("Cant move, on the right edge");
      return false;
    }
    for(uint8_t x = 0; x < nbRow; x++)
      {
        if (board[x][yBlock + sizeOfBlock] == SQUARE && board[x][yBlock] == MOVING_BLOCK)
        {
          Serial.println("Cant move, block in the way");
          return false;
        }
      }
  }
  return true;
}

void moveBlockLorR(char dir){

  if (dir == 'L')
  {
  for (uint8_t x = 0; x < nbRow; x++)
    for (uint8_t y = 0; y < nbCol; y++)
        if (board[x][y] == MOVING_BLOCK)
        {
          board[x][y-1] = MOVING_BLOCK;
          board[x][y] = EMPTY;          
        }
    yBlock -= 1;
  }
  else if (dir == 'R')
  {
  for (int x = nbRow; x > -1; x--)
    for (int y = nbCol; y > -1; y--)
        if (board[x][y] == MOVING_BLOCK)
        {
          board[x][y+1] = MOVING_BLOCK;
          board[x][y] = EMPTY;  
        }
    yBlock += 1;
  }
}

void deleteLine(){
  uint8_t nbSquare = 0;
  for (int x = nbRow; x > -1 ; x--)
  {
    nbSquare = 0;
    for (uint8_t y = 0; y < nbCol; y++)
      if (board[x][y] == SQUARE)
        nbSquare += 1;

    if (nbSquare == nbCol)
    {
      for (uint8_t i = 0; i < 3; i++)
      {
        for (uint8_t y2 = 0; y2 < nbCol; y2++)
          board[x][y2] = EMPTY;
        affichage();
        delay(LINE_CLEAR_DELAY);
        for (uint8_t y2 = 0; y2 < nbCol; y2++)
          board[x][y2] = SQUARE;
        affichage();
        delay(LINE_CLEAR_DELAY);
        for (uint8_t y2 = 0; y2 < nbCol; y2++)
          board[x][y2] = EMPTY;
        affichage();
        delay(LINE_CLEAR_DELAY);
      }
      score += 1; 
      for (uint8_t x2 = x + 1; x2 < nbRow; x2++)
        for (uint8_t y2 = 0; y2 < nbCol; y2++)
          board[x2 - 1][y2] = board[x2][y2];
    }
  }
}

void setup() 
{
  Serial.begin(9600);

  if (! ledmatrix.begin()) {
    Serial.println("IS31 not found");
    while (1);
  }
  Serial.println("IS31 found!");

  for (uint8_t x = 0; x < nbRow; x++)
    for (uint8_t y = 0; y < nbCol; y++)
      board[x][y] = 0;

  pinMode(BUTTON_LEF_PIN, INPUT);
  pinMode(BUTTON_MID_PIN, INPUT);
  pinMode(BUTTON_RIG_PIN, INPUT);
  
  startTime = millis();

}

void loop() 
{    
  affichage();

  deleteLine();

  if (!checkMovingBlock())
    createBlock();

  if (checkBlockDown())
    makeBlockDown();
  else
    stopBlock();

  checkGameOver();

  while((millis() - startTime) < speed)
  { 
    if (!digitalRead(BUTTON_LEF_PIN) && !digitalRead(BUTTON_MID_PIN) && !digitalRead(BUTTON_RIG_PIN))
    {
      for (uint8_t x = 0; x < nbRow; x++)
        for (uint8_t y = 0; y < nbCol; y++)
          board[x][y] = 0;
      delay(50);
    }
    else if (!digitalRead(BUTTON_LEF_PIN))
    {
      if(checkBlockLorR('L'))
      {      
        moveBlockLorR('L');
        affichage(); 
        delay(50);
      }
    }
    else if (!digitalRead(BUTTON_RIG_PIN))
    {
      if(checkBlockLorR('R'))
      {      
        moveBlockLorR('R');
        affichage(); 
        delay(50);
      }
    }
    else if (!digitalRead(BUTTON_MID_PIN))
    {
      delay(5);
      break;
    }
  }
  //Serial.print("Pos x (rows) : "); Serial.print(xBlock);  Serial.print(" Pos y (col) : "); Serial.println(yBlock);
  startTime = millis();
}

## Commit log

2025-12-24 Création de la fork et placement des fichiers déjà fait
    [BOM_C3i_TETRIS.xlsx, C3I_Atelier_KiCad.kicad_pcb, C3I_Atelier_KiCad.kicad_sch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]
2026-01-05 Ajout powerpoint
